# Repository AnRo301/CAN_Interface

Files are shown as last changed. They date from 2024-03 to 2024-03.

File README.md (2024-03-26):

# CAN Interface for ESP32

## Introduction

ESP32-Development-Boards contain powerful and inexpensive 32-bit microcontrollers and are well known for their low energy consumption. Due to their open design, the modules are well suited for (IoT) Internet of Things applications

CAN is a popular communication protocol in the automotive sector. It is a reliable and robust protocol which is designed for high-speed data transmission and real-time applications.
Although the microcontrollers have both CAN and Ethernet controllers integrated, there are currently no inexpensive boards available that provide an interface for the CAN bus.

Within this project, a circuit board is developed, which provides an interface between an ESP32 board and the CAN bus.

## Features

- Send and receive CAN Messages according to ISO11898-1
- Standard and extended frame format supported
- Various bus speeds supported
- Acts as a WLAN access point
- Received CAN messages are forwarded via web socket and can be viewed via a web interface on any device that is connected to the provided network
- Messages that are to be sent via the bus can be entered using the web interface and are transmitted via web socket to the microcontroller, which initiates the sending via CAN Bus

## Third Party Components
Hardware:
- esp32-s3-devkit-1
- USB-C cables
- SubD cable or twisted pair of jumper cables
- any device that supports wifi (computer/ tablet/ phone)

Software:
- Visual Studio Code
- Required Extension Packages:
  - PlatformIO IDE
  - Arduino
  - ESP-IDF
  
## How to run the project?
- Connect CAN Bus module to ESP32-S3 (pin labels must match)
grafik
- Connect to the CAN Bus either via SubD cable or via twisted pair of jumper cables (Pin Header: H (CAN High), L (CAN Low))
- Depending on the type of connection to the CAN bus (Subd or jumper cables) connect the pin headers via jumpers according to the following picture
  (A terminating resistor of 120 ohms is added between CAN High and CAN Low via JP1)
  
grafik
- Install extension packages mentioned in 'Third Party Components' in VS Code
- Connect ESP32-S3 via USB-C Port to the pc
- Build and Upload Filesystem Image with PlatformIO
- Connect ESP32-S3 via USB-C COM Port to the pc
- Build and upload the Code with PlatformIO
  
grafik

- Connect any device to the Wifi "CAN2WLAN" provided by the ESP32 acting as an access point
- Type in the following IP-Adresse in a browser: 192.168.4.1
- The following user interface should now appear:
  
Benutzeroberfläche04

Warning: Messages needs to be typed in in the right format. No detection of wrong/ unplausible input is implemented !

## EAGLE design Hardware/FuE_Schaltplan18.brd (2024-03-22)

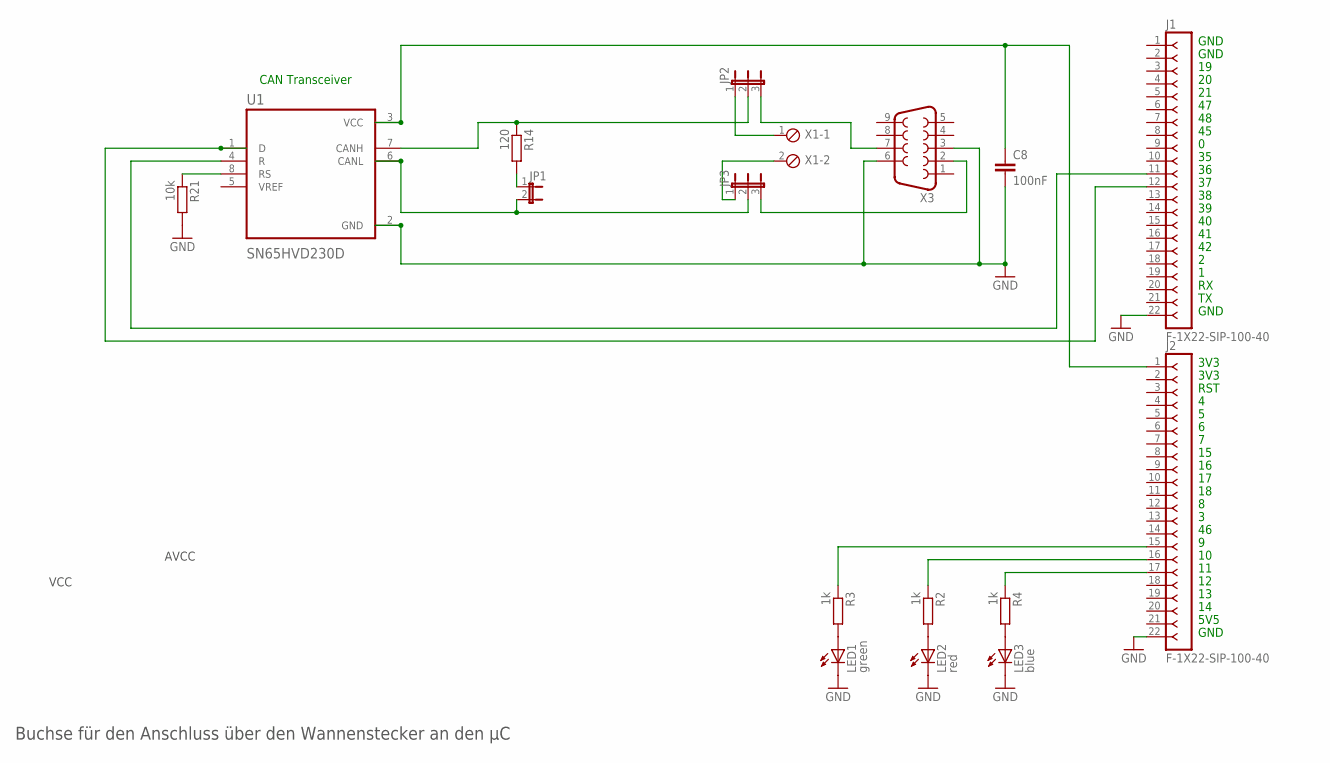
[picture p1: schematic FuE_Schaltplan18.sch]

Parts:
C8: 100nF; C0805
J1, J2: F-1X22-SIP-100-40; SIP-100-22-40
JP1: JP1E; JP1
JP2, JP3: JP2E; JP2
LED1: green; CHIP-LED0805
LED2: red; CHIP-LED0805
LED3: blue; CHIP-LED0805
R2, R3, R4: 1k; R0805
R14: 120; R0805
R21: 10k; R0805
U1: SN65HVD230D; SOIC127P599X175-8N
X1: MPT2; 2POL254
X3: F09VP

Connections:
GND: C8.2, J1.22, J2.22, LED1.C, LED2.C, LED3.C, R21.2, U1.2 (GND), X3.3, X3.6
unnamed: C8.1, J2.1, U1.3 (VCC)
unnamed: J1.11, U1.4 (R)
unnamed: LED2.A, R2.2
unnamed: R21.1, U1.8 (RS)
unnamed: JP1.2, JP3.2, U1.6 (CANL)
unnamed: J2.16, R2.1
unnamed: LED1.A, R3.2
unnamed: LED3.A, R4.2
unnamed: J2.15, R3.1
unnamed: J2.17, R4.1
unnamed: JP2.3, X3.7
unnamed: JP2.2, R14.1, U1.7 (CANH)
unnamed: J1.12, U1.1 (D)
unnamed: JP3.3, X3.2
unnamed: JP1.1, R14.2
unnamed: JP2.1, X1.1
unnamed: JP3.1, X1.2

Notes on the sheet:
AVCC
VCC
Buchse für den Anschluss über den Wannenstecker an den µC
CAN Transceiver
GND
3V3
RST
5V5

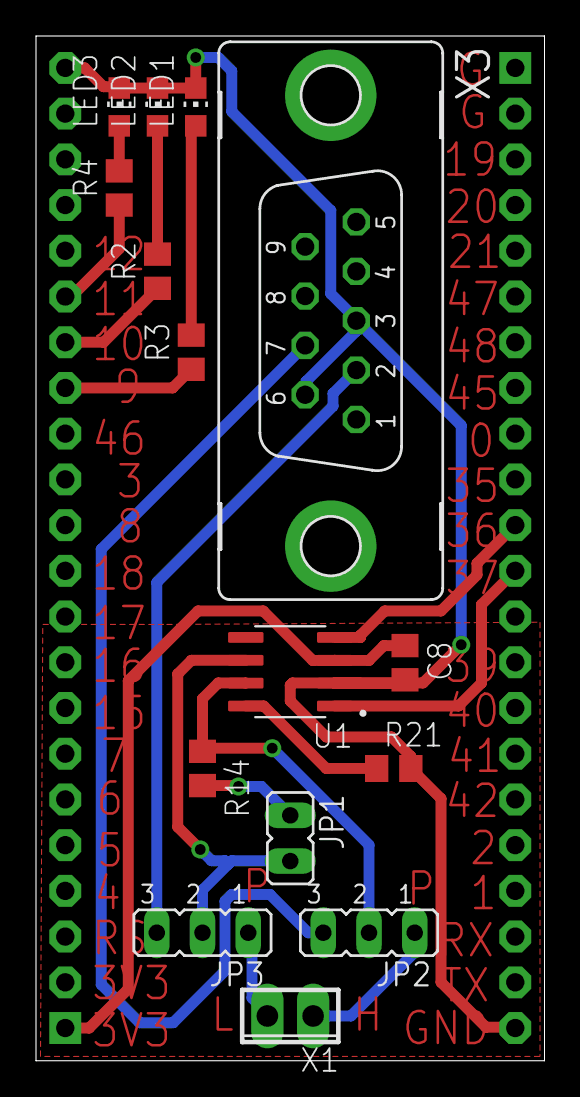
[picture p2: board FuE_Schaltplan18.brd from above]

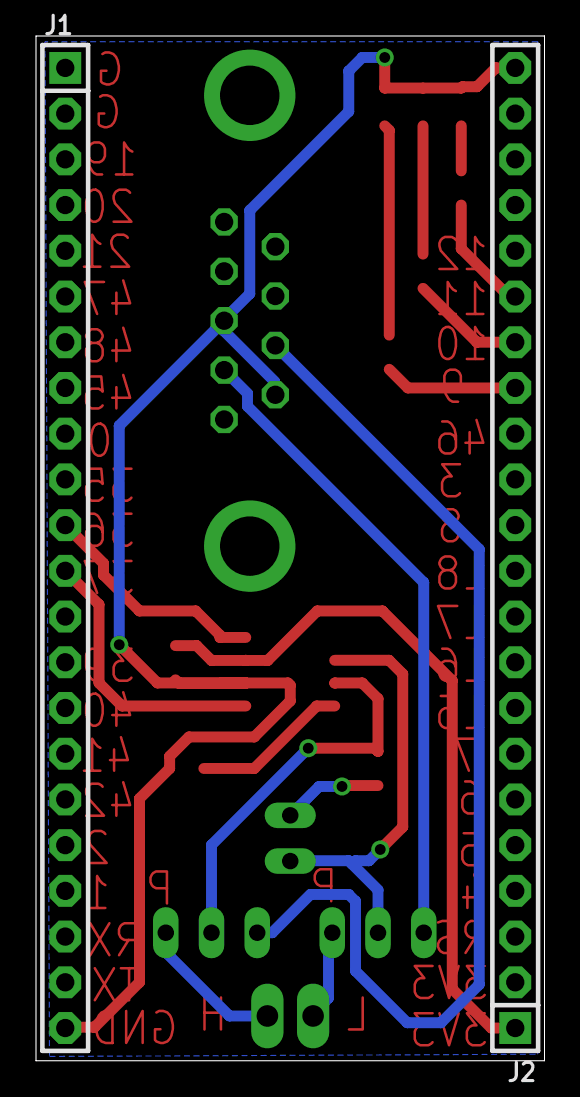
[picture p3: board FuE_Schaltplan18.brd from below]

Board: 2 copper layers, 28.2 x 56.9 mm, 17 parts (2 on the bottom side), 18 nets.

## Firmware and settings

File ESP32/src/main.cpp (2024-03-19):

#include <Arduino.h>
#include <vector>
#include <driver/gpio.h>
#include <sstream>
#include <iostream>

#include "Access_Point.h"
#include "CAN.h"

#include "driver/twai.h"
#include "freertos/FreeRTOS.h"
#include "freertos/task.h"
#include "freertos/semphr.h"
#include "esp_err.h"

using namespace std;


// /* --------------------------- Tasks and Functions -------------------------- */

void setup() {

  Serial.begin(9600);

  Init_AP();    //Init Access Points

  Init_WS();    // WebSocket-Handling

  Init_CAN();   // CAN

}

void loop() {
 
  twai_receive_task();

  WS_Handling();

}

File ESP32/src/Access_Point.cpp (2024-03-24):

#include <Access_Point.h>
#include <CAN.h>


/* --------------------- Definitions and static variables ------------------ */

WiFiUDP udp;
const char *ssid = "CAN2WLAN";
AsyncWebServer server(80);
AsyncWebSocket socket("/ws");

vector<uint8_t> b_read = {0x00, 0x00, 0x00, 0x00};
vector<uint8_t> receive_identifier = {0x00, 0x00, 0x00, 0x00, 0x00, 0x00, 0x00, 0x00};
vector<uint8_t> receive_data = {0x00, 0x00, 0x00, 0x00, 0x00, 0x00, 0x00, 0x00, 0x00, 0x00, 0x00, 0x00, 0x00, 0x00, 0x00, 0x00,};

/* --------------------------- Tasks and Functions -------------------------- */

void   Init_AP(){
  if(!SPIFFS.begin()){
    Serial.println("Failed to mount SPIFFS");
    return;
  }

  WiFi.softAP(ssid);

  Serial.print("Access Point IP-Adresse: ");
  Serial.println(WiFi.softAPIP());
}

void Init_WS(){

  socket.onEvent(onWsEvent);
  server.addHandler(&socket);

  server.on("/", HTTP_GET, [](AsyncWebServerRequest *request){
    serveFile(request, "/index.html", "text/html");
  });

  server.on("/style.css", HTTP_GET, [](AsyncWebServerRequest *request){
    serveFile(request, "/style.css", "text/css");
  });

  server.on("/script.js", HTTP_GET, [](AsyncWebServerRequest *request){
    serveFile(request, "/script.js", "application/javascript");
  });

  server.begin();
}

void sendReceivedCANData(CANFrame canFrame) {

  CANFrame canFrame4UDP;
  vector<uint8_t> id2 ={
         static_cast<uint8_t>(canFrame.identifier[3]),
         static_cast<uint8_t>(canFrame.identifier[2]),
         static_cast<uint8_t>(canFrame.identifier[1]),
         static_cast<uint8_t>(canFrame.identifier[0])};

  canFrame4UDP.identifier = canFrame.identifier; 
  canFrame4UDP.frameLength = canFrame.frameLength; 
  canFrame4UDP.data = canFrame.data; 
  canFrame4UDP.extFlag = canFrame.extFlag; 
  canFrame4UDP.rtrFlag = canFrame.rtrFlag;
  canFrame4UDP.identifier = {static_cast<uint8_t>(canFrame.identifier[3]),
                    static_cast<uint8_t>(canFrame.identifier[2]),
                    static_cast<uint8_t>(canFrame.identifier[1]),
                    static_cast<uint8_t>(canFrame.identifier[0])};

  vector<uint8_t> canFrameVec = CANFrame_to_Vec(canFrame4UDP);
  String canFrameString = CANFrame_to_JSON(canFrame);
      
  size_t canFrameLen = canFrameVec.size();

  BroadcastUDP(canFrameVec, canFrameLen);
  socket.textAll(canFrameString);

  delay(400);
}


void serveFile(AsyncWebServerRequest *request, const char *filename, const char *contentType) {
  File file = SPIFFS.open(filename, "r");
  if (!file) {
    Serial.println("Failed to open file for reading");
    request->send(404, "text/plain", "File not found");
    return;
  }

  String fileContent = file.readString();
  file.close();

  request->send(200, contentType, fileContent);
}


void onWsEvent(AsyncWebSocket * server, AsyncWebSocketClient * client, AwsEventType type, void * arg, uint8_t *data, size_t len){
 
  if(type == WS_EVT_CONNECT){
 
    Serial.println("Websocket client connection received");
    
    Serial.print("Client (IP: ");
    Serial.print(client->remoteIP());
    Serial.println(") connected.");
 
  } else if(type == WS_EVT_DISCONNECT){
    Serial.println("Client disconnected");
    Serial.println("-----------------------");
 
  } else if(type == WS_EVT_DATA){
 
    Serial.print("Data received: ");
 
    for(int i=0; i < len; i++) {
          Serial.print((char) data[i]);
    }
 
    Serial.println();
  }
}

std::vector<uint8_t> CANFrame_to_Vec(CANFrame canFrame ) {
    std::vector<uint8_t> canFrameVec;

    // Assemble CAN Frame Vector
    canFrameVec.insert(canFrameVec.end(), canFrame.magic.begin(), canFrame.magic.end());
    canFrameVec.insert(canFrameVec.end(), canFrame.version.begin(), canFrame.version.end());
    canFrameVec.insert(canFrameVec.end(), canFrame.framesCnt.begin(), canFrame.framesCnt.end());
    canFrameVec.insert(canFrameVec.end(), canFrame.identifier.begin(), canFrame.identifier.end());
    canFrameVec.insert(canFrameVec.end(), canFrame.frameLength.begin(), canFrame.frameLength.end());
    canFrameVec.insert(canFrameVec.end(), canFrame.data.begin(), canFrame.data.end());
    canFrameVec.insert(canFrameVec.end(), canFrame.extFlag.begin(), canFrame.extFlag.end());
    canFrameVec.insert(canFrameVec.end(), canFrame.rtrFlag.begin(), canFrame.rtrFlag.end());
    canFrameVec.insert(canFrameVec.end(), canFrame.options.begin(), canFrame.options.end());

    return canFrameVec;
}

String vectorToHexString(const std::vector<uint8_t>& vec) {
    String result;
    for (size_t i = 0; i < vec.size(); ++i) {
        // Convert each value to a two-digit hexadecimal string
        result += String(vec[i], HEX);

        // Add a space between every two characters, except for the last character
        if (i < vec.size() - 1) {
            result += " ";
        }
    }
    return result;
}

String CANFrame_to_JSON (CANFrame canFrame){

  DynamicJsonDocument doc(256);

  doc["identifier"] = vectorToHexString(canFrame.identifier);
  doc["frameLength"] = vectorToHexString(canFrame.frameLength);
  doc["data"] = vectorToHexString(canFrame.data);
  doc["extFlag"] = vectorToHexString(canFrame.extFlag);
  doc["rtrFlag"] = vectorToHexString(canFrame.rtrFlag);

  String CANString;
  serializeJson(doc, CANString);

  return CANString;
}


void BroadcastUDP(std::vector<uint8_t> data, size_t len) {
  udp.beginPacket("255.255.255.255", 1060);
  udp.write(data.data(), len);
  udp.endPacket();
}


uint8_t combineDigits(uint8_t num1, uint8_t num2) { // Die letzten 4 Bits jeder Zahl extrahieren 
    uint8_t last4BitsNum1 = num1 & 0x0F; 
    uint8_t last4BitsNum2 = num2 & 0x0F; // Die letzten 4 Bits von num1 nach links verschieben und mit den letzten 4 Bits von num2 kombinieren 
    uint8_t combinedNum = (last4BitsNum1 << 4) | last4BitsNum2; 
    return combinedNum; 
}
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

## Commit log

2024-03-19 modified: ESP32/src/main.cpp
2024-03-21 modified: ESP32/include/Access_Point.h
2024-03-22 modified: ESP32/data/index.html modified: ESP32/data/script.js modified: ESP32/data/style.css modified: ESP32/include/CAN.h modified: ESP32/src/Access_Point.cpp modified: ESP32/src/CAN.cpp
2024-03-23 modified: ESP32/src/Access_Point.cpp modified: ESP32/src/CAN.cpp
2024-03-24 modified: ESP32/data/index.html modified: ESP32/data/script.js modified: ESP32/include/Access_Point.h modified: ESP32/include/CAN.h modified: ESP32/src/Access_Point.cpp modified: ESP32/src/CAN.cpp
2024-03-25 modified: ESP32/data/script.js

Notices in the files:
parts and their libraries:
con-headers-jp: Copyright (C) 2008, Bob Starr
